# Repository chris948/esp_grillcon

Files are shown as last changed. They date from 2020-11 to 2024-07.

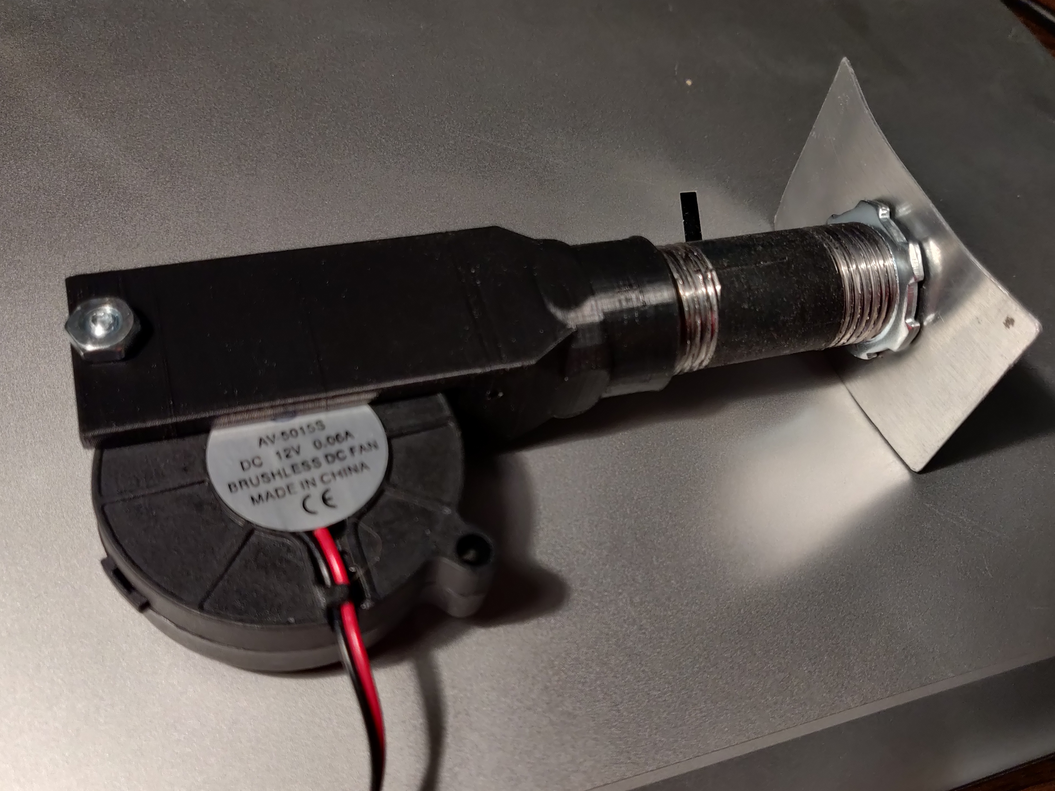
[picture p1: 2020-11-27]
IMG_20200713_215710__01.jpg

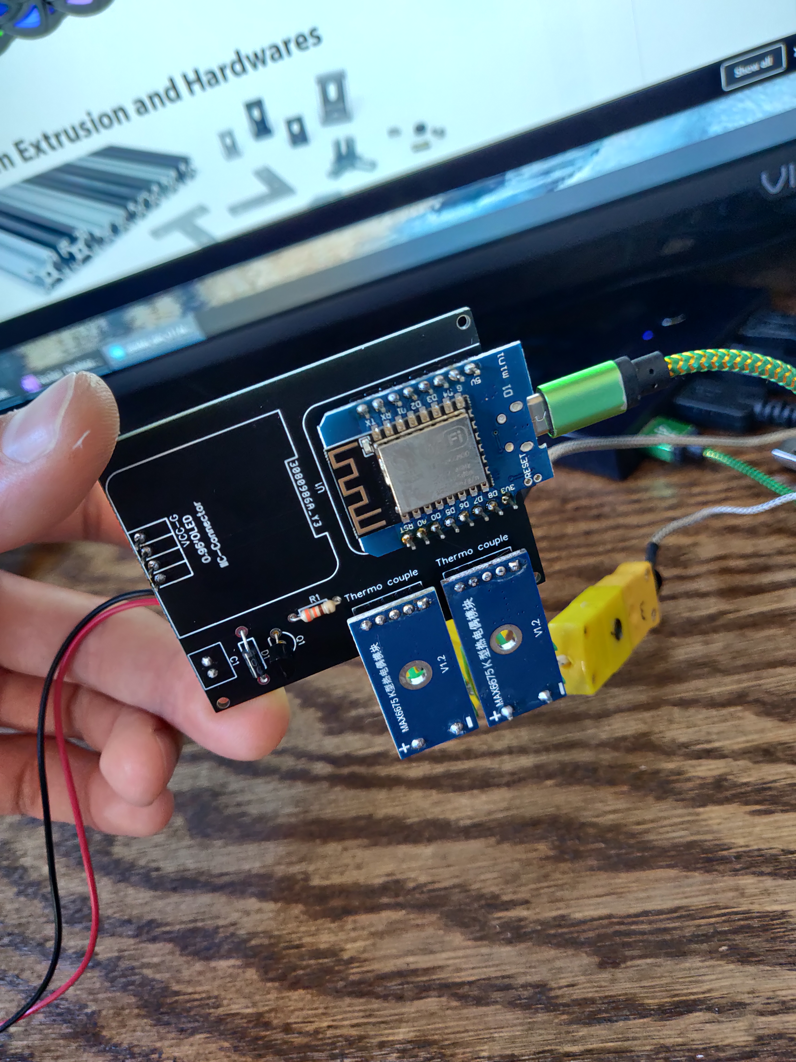
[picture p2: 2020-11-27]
IMG_20200624_134615.jpg

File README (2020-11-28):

grill controller for esp8266.

The diode label on the pcb is reversed. Install it backwards from the pcb print.

BOM

2x Type k thermocouples

2x max6675 https://www.aliexpress.com/item/32853251306.html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,searchweb201602_,searchweb201603_

.96 inch lcd screen,https://www.aliexpress.com/item/32638662748.html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,searchweb201602_,searchweb201603_

D1 Mini https://www.aliexpress.com/item/32643142716.html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,searchweb201602_,searchweb201603_

1k ohm resistor
 
1N4007 diode

2N2222A transistor

50x15mm blower fan

Optional

Thermocouple Connector, Panel Jack, MPJ Series, Type K, Socket

https://www.newark.com/newport-electronics/mpj-k-f-rohs/miniature-panel-socket-k-type/dp/64X9318

https://www.auberins.com/index.php?main_page=product_info&products_id=247

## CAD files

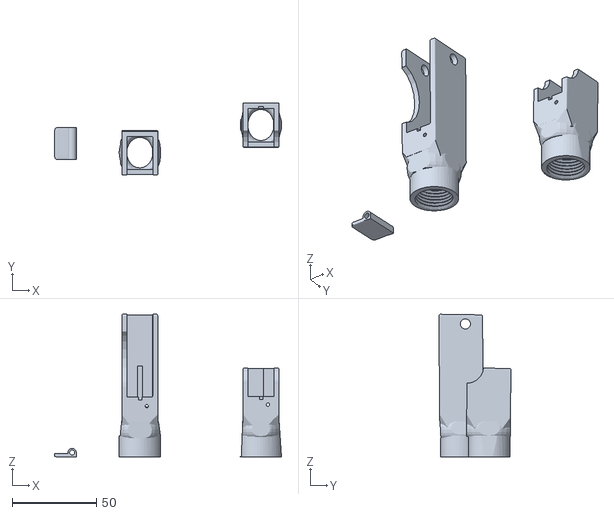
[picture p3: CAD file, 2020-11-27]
grillcon_v1_fan.stl
135.0 x 43.0 x 84.8

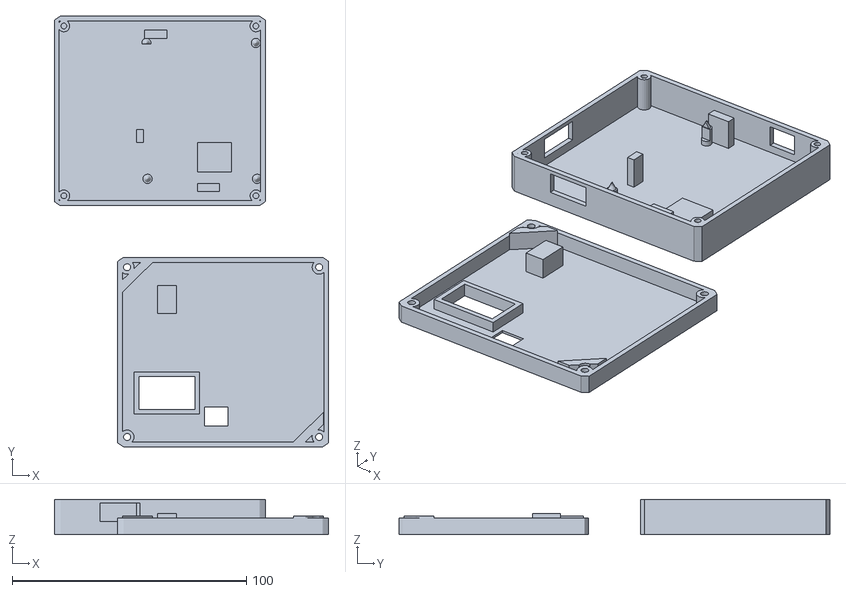
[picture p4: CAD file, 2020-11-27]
grill_control_box_v1.stl
117.0 x 184.0 x 15.0

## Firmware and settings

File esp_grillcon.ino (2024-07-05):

extern "C" 
{
#include "user_interface.h"
} 

#include <FS.h>
#include "max6675.h"
#include <SPI.h>
#include <Wire.h>
//#include <Adafruit_GFX.h>
#include <Adafruit_SSD1306.h>

#include <ESP8266WiFi.h>          //https://github.com/esp8266/Arduino

//needed for library
//#include <ArduinoOTA.h>
#include <DNSServer.h>
#include <WiFiManager.h>         //https://github.com/tzapu/WiFiManager
#include <ArduinoJson.h>
#include <ESP8266mDNS.h>
#include <NTPClient.h>
#include <WiFiUdp.h>
#include <TimeLib.h> 
#include <WiFiClient.h>
#include <ESP8266WebServer.h>
#include <WebOTA.h>


//todo
//email/text alerts?
//break up html file size


#define ALLOCATED_RAM 33520
unsigned long numberOfRows=0;

unsigned long timer = 0;
unsigned long writeTimer = 0;

WiFiUDP ntpUDP;

// You can specify the time server pool and the offset, (in seconds)
// additionaly you can specify the update interval (in milliseconds).
// NTPClient timeClient(ntpUDP, "europe.pool.ntp.org", 3600, 60000);
//-18000 = 5 hours,
//-21600 = 6 hours
int timeZoneOffset = -18000;
NTPClient timeClient(ntpUDP, "0.north-america.pool.ntp.org", timeZoneOffset, 60000);

//char jsonStatusMsg[140];

//configuration properties
int tempDif = 3;
int fanMin = 6;
int dispC =0;
//char emailUsername[150];
//char emailPassword[150];
//char emailSendTo[150];
//int alertOn = ALERTON;
//int emailAfter = EMAILAFTER;
int writeDuration = 120000; // 5 mins = 300000 millis, 3 mins = 180000, 2 mins = 120000

char hostname[20];

//SCL and SDA are used for the screen
//SCL D1
//SDA D2

int thermoDO = 12; //D6
int thermoCS0 = 15; //D8
int thermoCS1 = 16; //D0
int thermoCLK = 14; //D5

int fanPin = 13; //D7

//grill
MAX6675 thermocouple0(thermoCLK, thermoCS0, thermoDO);
//meat
MAX6675 thermocouple1(thermoCLK, thermoCS1, thermoDO);

int my_target_grill_temp = 0;
int my_current_grill_temp = 0;
int my_current_meat_temp = 0;
int my_state = 0;
int my_fan_speed = 0;

//graph data
int rowCount = 0;
String *timeStamp;
int *grillTemp;
int *meatTemp;

///lcd
#define SCREEN_WIDTH 128 // OLED display width, in pixels
#define SCREEN_HEIGHT 64 // OLED display height, in pixels

// Declaration for an SSD1306 display connected to I2C (SDA, SCL pins)
#define OLED_RESET     -1 // Reset pin # (or -1 if sharing Arduino reset pin)
Adafruit_SSD1306 display(SCREEN_WIDTH, SCREEN_HEIGHT, &Wire, OLED_RESET);
  

void setup() {
  Serial.begin(115200);

  sprintf (hostname, "smoker");
  //start lcd screen
  lcdSetup();
  
  //start wifi
  wifiSetup();
  mdnsSetup();
  webServerSetup();

  //webota
  // To use a specific port and path uncomment this line
  // Defaults are 8080 and "/webota"
  //webota.init(8888, "/update");
  
  //load config file
  configLoad();
  
  //get ntp time
  timeClient.begin();
  
  //timers for the loop
  timer = millis();
  writeTimer = millis();
  
  //determine free space and initialize arrays
  allocateRam();
  
  //load previous cook data if possible
  cookLoad();
  
  Serial.println("finished setup");
}//end setup

void loop() {

   
   webServerLoop();
   //webota
   webota.handle();

   if (rowCount % 2 == 0){
    checkMem();
   }

   //get temps and update variables for LCD and website based on timer value
   if (millis()>=timer){
    timer = millis() + 3000;

    getTempF();
    
     if (my_state == 1){
      controlFan();
      logCook();
     }
     else {
      my_fan_speed = 0;
      analogWrite(fanPin, 0);
     }

     lcdWrite();
   } 
}//finish loop


//checks to see if the array is getting full. If so, overwrites rows, deleting every other entry
void checkMem(){
  if ((rowCount + 16) > numberOfRows){
    Serial.println("entering checkmem loop");
    Serial.println(rowCount);

//i=2 leaves the first entry, preserving cook start time
    for (int i = 2; i< (rowCount / 2) ; i++){

      int newRow = (i * 2) - 1;
      Serial.print("new row is ");
      Serial.println(newRow);
      timeStamp[i] = timeStamp[newRow];
      Serial.print("timestamp is ");
      Serial.println(timeStamp[newRow]);
      grillTemp[i] = grillTemp[newRow];
      Serial.print("grilltemp is ");
      Serial.println(grillTemp[newRow]);
      meatTemp[i] = meatTemp[newRow];
      Serial.print("meat temp is ");
      Serial.println(meatTemp[newRow]);
    }
    //reset rowCount to the new, smaller number so any new writes will start after this culling
    rowCount = (rowCount / 2);
    //double writeDuration to match the half of values left in our history
    writeDuration += writeDuration;

    Serial.println("leaving checkmem loop");
    Serial.println(rowCount);
  }
}

void controlFan(){

  int my_tempDif = my_target_grill_temp - my_current_grill_temp;
  
  if (my_tempDif > tempDif){
    
    my_fan_speed = (sqrt(my_tempDif) + fanMin) * 100;

    if (my_fan_speed > 1023){
      my_fan_speed = 1023;
    }
  }
  else {
    my_fan_speed = 0;
  }

  Serial.print("Max Temp Difference is ");  
  Serial.println(tempDif);
  Serial.print("Temp Difference is ");
  Serial.println(my_tempDif);
  //Serial.print("Fan Speed Is ");
  //Serial.println(my_fan_speed);
  //fanspeed here
  analogWrite(fanPin, my_fan_speed);
}


void getTempF(){

  if (dispC == 0){
      my_current_grill_temp = thermocouple0.readFahrenheit();
      my_current_meat_temp = thermocouple1.readFahrenheit();
  }
  else {
      my_current_grill_temp = thermocouple0.readCelsius();
      my_current_meat_temp = thermocouple1.readCelsius();   
  }

  

  if (isnan(my_current_grill_temp) or my_current_grill_temp == 2147483647) {
    my_current_grill_temp = 0;
  }
  if (isnan(my_current_meat_temp) or my_current_meat_temp == 2147483647) {
    my_current_meat_temp = 0;
  }
}

void logCook(){
  
  if (millis() >= writeTimer) {
    
    //ntp time
    timeClient.update();
    
    Serial.println(timeClient.getFormattedTime());
  
    writeTimer = millis() + writeDuration;
    timeStamp[rowCount] = timeClient.getFormattedTime();  //Current time
    grillTemp[rowCount] = my_current_grill_temp;
    meatTemp[rowCount] = my_current_meat_temp;

    Serial.print(" writing to memory - current time ");
    Serial.println(timeStamp[rowCount]);
    Serial.print("grill temp ");
    Serial.println(grillTemp[rowCount]);
    Serial.print("meat temp ");
    Serial.println(meatTemp[rowCount]);
    Serial.print("counter is ");
    Serial.println(rowCount);

    rowCount++;
  }
}


void allocateRam(){
  //Get free RAM in bytes
  uint32_t free=system_get_free_heap_size() - ALLOCATED_RAM;

  
  //Divide the free RAM by the size of the variables used to store the data. 
  //This will allow us to work out the maximum number of records we can store. 
  //All while keeping some RAM free which is specified in ALLOCATED_RAM
  numberOfRows = free / (sizeof(int)*2+ sizeof(unsigned long)); // 2 x int for temps.  Long for time. 

  Serial.print("Space for ");
  Serial.print(numberOfRows);
  Serial.println(" rows");

  //re-declare the arrays with the number of elements
  grillTemp = new int [numberOfRows];
  meatTemp = new int [numberOfRows];
  timeStamp = new String [numberOfRows];

}

void factoryReset() {
  Serial.println("Restoring Factory Setting....");
  WiFi.disconnect();
  SPIFFS.format();
  ESP.eraseConfig();
  Serial.println("Restarting....");
  delay(500);
  ESP.restart();
}

void cookSave() {
  DynamicJsonDocument jsonDoc(64);
  JsonObject json = jsonDoc.to<JsonObject>();

  //save in case of esp8266 reboot
  json["my_target_grill_temp"] = my_target_grill_temp;
  json["my_state"] = my_state;

  File cookFile = SPIFFS.open("/cook.json", "w");
  if (cookFile) {
    Serial.println("Saving cook data....");
    serializeJson(json, Serial);
    Serial.println();
    serializeJson(json, cookFile);
    cookFile.close();
  }
}


//Loads the configuration data on start up
void cookLoad() {
  Serial.println("Loading cook data from cookLoad");
  if (SPIFFS.begin()) {
    if (SPIFFS.exists("/cook.json")) {
      //file exists, reading and loading
      File cookFile = SPIFFS.open("/cook.json", "r");
      if (cookFile) {
        size_t size = cookFile.size();
        std::unique_ptr<char[]> buf(new char[size]);

        cookFile.readBytes(buf.get(), size);

        DynamicJsonDocument jsonDoc(size);
        DeserializationError error = deserializeJson(jsonDoc, buf.get());
        serializeJsonPretty(jsonDoc, Serial);

        JsonObject json = jsonDoc.as<JsonObject>();
        if (json.containsKey("my_target_grill_temp")) {
          my_target_grill_temp = json["my_target_grill_temp"];
        }

        if (json.containsKey("my_state")) {
          my_state = json["my_state"];
        }
      }
    }
  }
}

void configSave() {
  DynamicJsonDocument jsonDoc(128);
  JsonObject json = jsonDoc.to<JsonObject>();

  json["tempDif"] = tempDif;
  json["fanMin"] = fanMin;
  json["timeZoneOffset"] = timeZoneOffset;
  json["dispC"] = dispC;

  File configFile = SPIFFS.open("/config.json", "w");
  if (configFile) {
    Serial.println("Saving config data....");
    serializeJson(json, Serial);
    Serial.println();
    serializeJson(json, configFile);
    configFile.close();
    Serial.println("exiting config save");
  }
}

//Loads the configuration data on start up
void configLoad() {
  Serial.println("Loading config data from configLoad");
  if (SPIFFS.begin()) {
    if (SPIFFS.exists("/config.json")) {
      //file exists, reading and loading
      File configFile = SPIFFS.open("/config.json", "r");
      if (configFile) {
        size_t size = configFile.size();
        std::unique_ptr<char[]> buf(new char[size]);

        configFile.readBytes(buf.get(), size);

        DynamicJsonDocument jsonDoc(size);
        DeserializationError error = deserializeJson(jsonDoc, buf.get());
        Serial.println("testbeforepretty");
        serializeJsonPretty(jsonDoc, Serial);
        Serial.println("testafterpretty");

        JsonObject json = jsonDoc.as<JsonObject>();
        if (json.containsKey("tempDif")) {
          tempDif = json["tempDif"];
        }

        if (json.containsKey("fanMin")) {
          fanMin = json["fanMin"];
        }
        
         if (json.containsKey("timeZoneOffset")) {
          //Serial.print("time zone offset received ");
          timeZoneOffset = json["timeZoneOffset"];
          //Serial.println(timeZoneOffset);
          timeClient.setTimeOffset(timeZoneOffset);
        }     
        if (json.containsKey("dispC")) {
          Serial.println("found dispC in configLoad");
          dispC = json["dispC"];
        }  
      }
    }
  }
}

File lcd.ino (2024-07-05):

void lcdSetup(){

    // SSD1306_SWITCHCAPVCC = generate display voltage from 3.3V internally
  if(!display.begin(SSD1306_SWITCHCAPVCC, 0x3C)) { // Address 0x3D for 128x64
    Serial.println(F("SSD1306 allocation failed"));
    for(;;); // Don't proceed, loop forever
  }

  // Show initial display buffer contents on the screen --
  // the library initializes this with an Adafruit splash screen.
  display.display();
  delay(2000); // Pause for 2 seconds

  // Clear the buffer
  display.clearDisplay();

  // Draw a single pixel in white
  display.drawPixel(10, 10, SSD1306_WHITE);

  // Show the display buffer on the screen. You MUST call display() after
  // drawing commands to make them visible on screen!
  display.display();
  delay(2000);
  display.clearDisplay();

  //display.setFont(&FreeMono9pt7b);
  display.setTextSize(1);
  display.setTextColor(WHITE);
  display.setCursor(0, 0);


}

void lcdWifiBroadcast(String msg){
   Serial.print("Broadcasting SSID");
   display.clearDisplay();
   display.setTextSize(1);
   display.setCursor(0, 0);
   display.print("Connect to AP ");
   display.print("\n");
   display.print(msg);
   
   display.display(); 
}

void lcdWrite(){

   //Serial.print("F = ");
   //Serial.println(my_current_grill_temp);
   display.clearDisplay();
   display.setTextSize(2);
   display.setCursor(0, 0);
   display.print("Grill ");
   display.print(my_current_grill_temp);
   display.print("\n");
   display.print("Meat ");
   display.print(my_current_meat_temp);
   display.print("\n");
   display.setTextSize(1);
   display.print("\n");
   //display.print("Status: ");
   display.print("Power: ");
   if (my_state == 1){
    display.print("On ");
    display.print("Target: ");
    display.print(my_target_grill_temp);
   }
   else {
    display.print("Off ");
   }
   display.print("\n");
   display.print("IP:");
   display.print(WiFi.localIP());
   //Serial.print(WiFi.localIP());
   display.display(); 
   
}

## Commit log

2020-07-16 google charts and bug fixes
    [configuration.h]
2020-08-16 removing unused file
    [configuration.h]
2020-11-27 added pcb file, stls for case and fan adaptor.
    [grill_control_box_v1.stl, grillcon_v1_fan.stl]
